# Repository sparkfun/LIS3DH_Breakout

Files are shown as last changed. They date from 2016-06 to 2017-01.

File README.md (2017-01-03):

SparkFun Triple Axis Accelerometer Breakout - LIS3DH
=============================================

SparkFun Triple Axis Accelerometer Breakout - LIS3DH  

[*SparkFun Triple Axis Accelerometer Breakout - LIS3DH(SEN-13963)*](https://www.sparkfun.com/products/13963)

This breakout board makes it easy to use the tiny LIS3DH accelerometer in your project. 
The LIS3DH is a smart low-power, three-axis, capacitive micro-machined accelerometer with 12 bits of resolution.

This product replaced the MMA-8452Q.

Repository Contents
-------------------
* **/Hardware** - All Eagle design files (.brd, .sch)
* **/Libraries** - Libraries for use with the <PRODUCT NAME>
* **/Production** - Production panel files (.brd)

Documentation
--------------
* **[Library](https://github.com/sparkfun/SparkFun_LIS3DH_Arduino_Library)** - Arduino library.
* **[Hookup Guide](https://learn.sparkfun.com/tutorials/lis3dh-hookup-guide)** - Basic hookup guide.
* **[SparkFun Fritzing repo](https://github.com/sparkfun/Fritzing_Parts)** - Fritzing diagrams for SparkFun products.
* **[SparkFun 3D Model repo](https://github.com/sparkfun/3D_Models)** - 3D models of SparkFun products. 
* **[SparkFun Graphical Datasheets](https://github.com/sparkfun/Graphical_Datasheets)** -Graphical Datasheets for various SparkFun products.

Version History
---------------
* [V_0.1](https://github.com/sparkfun/LIS3DH_Breakout/tree/V_0.1) - Prototype
* [V_H1.0_L1.0.0](https://github.com/sparkfun/LIS3DH_Breakout/tree/V_H1.0_L1.0.0) - Hardware version 1.0, library version 1.0.0. 

License Information
-------------------

This product is _**open source**_! 

Please review the LICENSE.md file for license information. 

If you have any questions or concerns on licensing, please contact techsupport@sparkfun.com.

Distributed as-is; no warranty is given.

- Your friends at SparkFun.

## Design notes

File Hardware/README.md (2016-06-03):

SparkFun <PRODUCT NAME> Design Files
=====================================

The .sch and .brd files hare are Eagle CAD schematic and PCB design files from SparkFun Electronics.
A freeware version of Eagle can be found [here](http://www.cadsoftusa.com/download-eagle/freeware/). 

License
---------
This product is open source! 
The hardware is released under [Creative Commons ShareAlike 4.0 International](https://creativecommons.org/licenses/by-sa/4.0/).

Please use, reuse, and modify these files as you see fit. Please maintain attribution to SparkFun Electronics and release anything derivative under the same license.

Distributed as-is; no warranty is given.

- Your friends at SparkFun.

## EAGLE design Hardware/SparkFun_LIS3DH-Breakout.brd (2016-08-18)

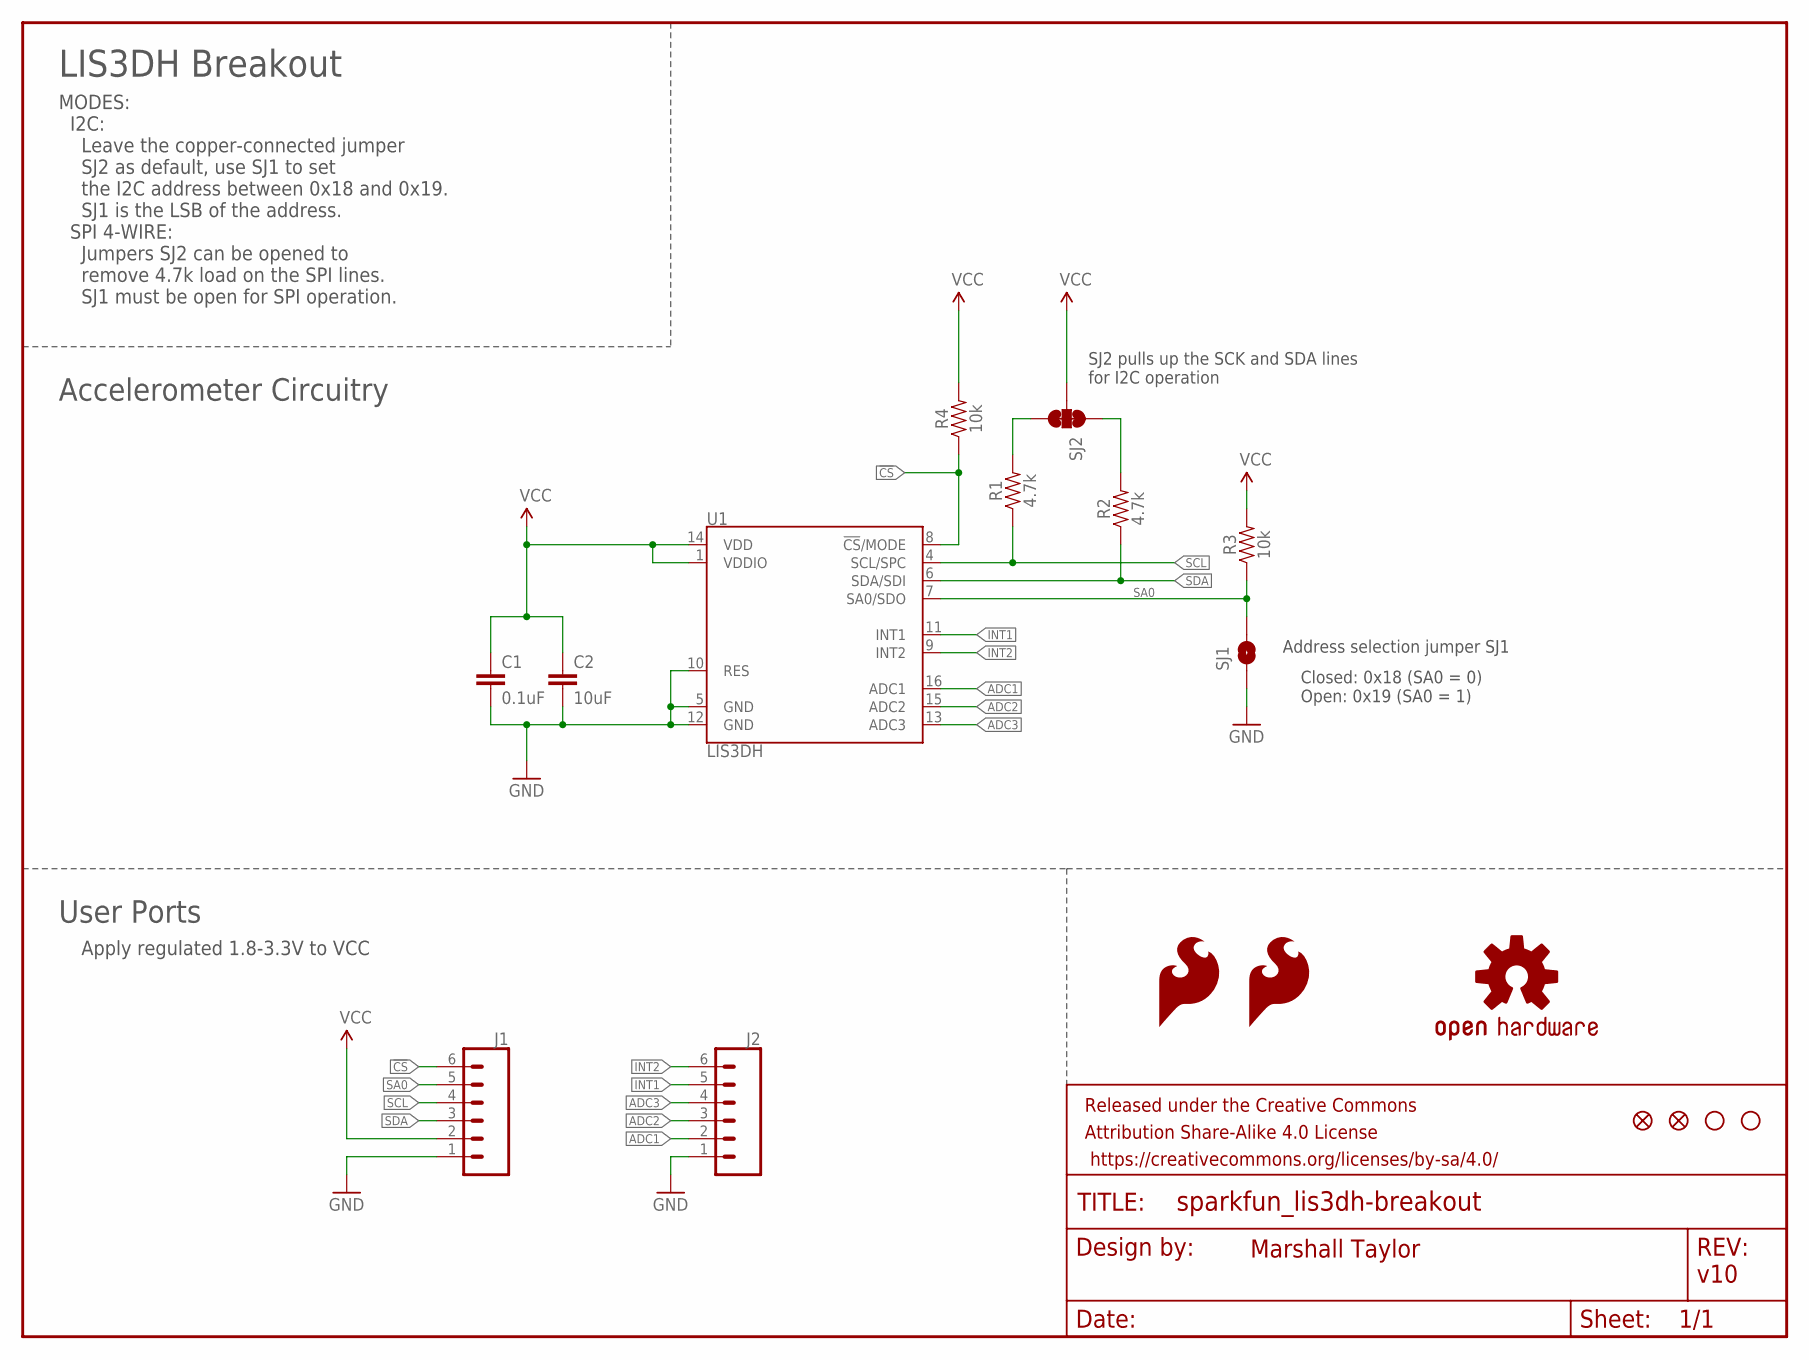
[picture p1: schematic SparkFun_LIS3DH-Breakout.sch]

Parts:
C1: 0.1uF; 0402
C2: 10uF; 0603
FRAME2: FRAME-LETTER; CREATIVE_COMMONS
J1, J2: CONN_06NO_SILK_FEMALE_PTH; 1X06_NO_SILK
JP2, JP6: FIDUCIALUFIDUCIAL; MICRO-FIDUCIAL
JP3, JP4: STAND-OFF
LOGO1, LOGO2: SFE_LOGO_FLAME.1_INCH; SFE_LOGO_FLAME_.1
R1, R2: 4.7k; 0603
R3, R4: 10k; 0603
SJ1: SOLDERJUMPERNO; SJ_2S-NO
SJ2: JUMPER-PAD-3-NC_BY_TRACE; PAD-JUMPER-3-3OF3_NC_BY_TRACE_YES_SILK_FULL_BOX
U1: LIS3DH; LGA-16-3X3
U$1: OSHW-LOGOS; OSHW-LOGO-S

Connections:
!CS: J1.6, R4.1, U1.8 (!CS!/MODE)
ADC1: J2.2, U1.16 (ADC1)
ADC2: J2.3, U1.15 (ADC2)
ADC3: J2.4, U1.13 (ADC3)
GND: C1.2, C2.2, J1.1, J2.1, SJ1.1, U1.5 (GND), U1.10 (RES), U1.12 (GND)
INT1: J2.5, U1.11 (INT1)
INT2: J2.6, U1.9 (INT2)
unnamed: R2.2, SJ2.1
unnamed: R1.2, SJ2.3
SA0: J1.5, R3.1, SJ1.2, U1.7 (SA0/SDO)
SCL: J1.4, R1.1, U1.4 (SCL/SPC)
SDA: J1.3, R2.1, U1.6 (SDA/SDI)
VCC: C1.1, C2.1, J1.2, R3.2, R4.2, SJ2.2, U1.1 (VDDIO), U1.14 (VDD)

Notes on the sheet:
Closed: 0x18 (SA0 = 0) Open: 0x19 (SA0 = 1)
Address selection jumper SJ1
v10
Marshall Taylor
LIS3DH Breakout
SJ2 pulls up the SCK and SDA lines for I2C operation
MODES: I2C: Leave the copper-connected jumper SJ2 as default, use SJ1 to set the I2C address between 0x18 and 0x19. SJ1 is the LSB of the address. SPI 4-WIRE: Jumpers SJ2 can be opened to remove 4.7k load on the SPI lines. SJ1 must be open for SPI operation.
Accelerometer Circuitry
User Ports
Apply regulated 1.8-3.3V to VCC

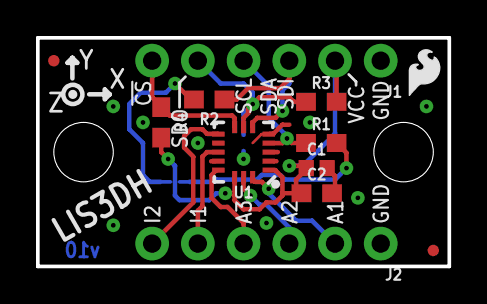
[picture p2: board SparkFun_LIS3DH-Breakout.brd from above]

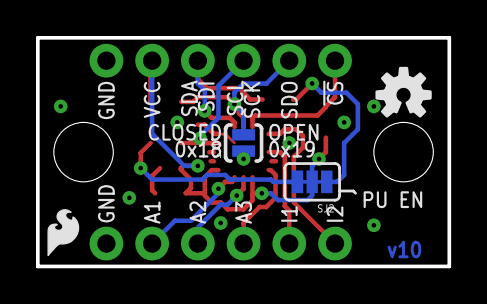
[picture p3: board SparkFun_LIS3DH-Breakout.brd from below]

Board: 2 copper layers, 22.9 x 12.7 mm, 19 parts (4 on the bottom side), 13 nets.

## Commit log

2016-06-03 Initial commit - Hardware copied from MMA-8452Q repo
    [SparkFun_MMA8452Q-Breakout.brd, SparkFun_MMA8452Q-Breakout.sch]
2016-06-07 Implanted LIS3DH into previous design, renamed files but basically the design is still really the old design with the new IC. This is a turning point before adding more features. Also, the gitignore 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
    [SparkFun_LIS3DH-Breakout.brd, SparkFun_LIS3DH-Breakout.sch, SparkFun_MMA8452Q-Breakout.brd]
2016-06-07 Finished design for proto 1
    [SparkFun_LIS3DH-Breakout.brd, SparkFun_LIS3DH-Breakout.sch]
2016-06-09 Updated design based off design review
    [SparkFun_LIS3DH-Breakout.brd, SparkFun_LIS3DH-Breakout.sch]
2016-06-09 Adjusted a trace and updated components to most recent libraries
    [SparkFun_LIS3DH-Breakout.brd, SparkFun_LIS3DH-Breakout.sch]
2016-06-09 fixed airwire and renamed C3 to C2
    [SparkFun_LIS3DH-Breakout.brd, SparkFun_LIS3DH-Breakout.sch]
2016-08-17 Fixed silk: added address/jumper function, pumped up the product name silk. Swapped I1 and I2. Added more topside labeling
    [SparkFun_LIS3DH-Breakout.brd, SparkFun_LIS3DH-Breakout.sch]
2016-08-17 removed 'ADR' and : silks
    [SparkFun_LIS3DH-Breakout.brd, SparkFun_LIS3DH-Breakout.sch]
2016-08-18 Applied review changes
    [SparkFun_LIS3DH-Breakout.brd, SparkFun_LIS3DH-Breakout.sch]
2017-01-03 Squashed 'Libraries/Arduino/' content from commit 7dddbcc
    git-subtree-dir: Libraries/Arduino
    git-subtree-split: 7dddbcca47f75477a0a8c26ba2455d239bf04937

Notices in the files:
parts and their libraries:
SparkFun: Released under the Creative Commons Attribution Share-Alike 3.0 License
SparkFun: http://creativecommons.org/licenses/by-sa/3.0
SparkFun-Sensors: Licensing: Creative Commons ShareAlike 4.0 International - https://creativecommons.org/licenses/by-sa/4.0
